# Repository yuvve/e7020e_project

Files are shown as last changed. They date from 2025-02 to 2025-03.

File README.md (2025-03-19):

# Sea Breeze Clock

The Sea Breeze Clock provides ultimate comfort for deep sleepers. Featuring a built-in humidifier, temperature sensor displayed on screen, and a gentle wake-up vibration function, it is designed to help you start your day feeling refreshed as if you have woken up on a private island.

## Members

- Yuval Levy (yuvlev-1@student.ltu.se)
- Calle Rautio (calrau-1@student.ltu.se)
- Simon Larsson (simlar-0@student.ltu.se)

## Hardware Features

- Display
- Humidifier for sea effect
- Backup battery for RTC and alarm time
- Speaker
- User interface (encoder / button)
- Programming interface
- Temperature measurement
- Fan for (hamster sized) sea breeze effect
- USB MINI connection
- Haptic actuator for SUPER GENTLE WAKE
- Hard(ish) protective case for the board

## Functionality and SW features

Besides mandatory functionality the Final Countdown features:

- Set Clock with long push and alarm time with short push. Change of volume with rotary button on default screen.
- CLI can control temperature sensor, speaker volume, intensity of buzzer, and fan speed control from CLI, and everything else.
- Maybe additional features.

## Individual grading goals and contributions

### Yuval Levy
#### 3 
- Contribute to the mandatory goals
#### 4
- Backup battery (HW & SW)
- Haptic actuator (HW & SW)
#### 5 
- Speaker (HW & SW)
- Power optimization (SW)
- Humidifier HW

### Calle Rautio
#### 3 
- Contribute to the mandatory goals
#### 4
- Humidifier SW
- Fan HW
- Fan SW
- HW component optimization (fewer MOSFETS)
#### 5 
- Speaker (HW & SW)

### Simon Larsson
#### 3 
- Contribute to the mandatory goals
#### 4
- Backup battery (HW & SW)
- Temperature on display SW
- Rotary encoder HW
#### 5 
- Speaker (HW & SW)
- Rotary encoder SW
- Power optimization (SW)

## HW References

- [MCU (QDAA QFN40)](https://docs.nordicsemi.com/bundle/ps_nrf52833/page/keyfeatures_html5.html) (**included**)
- [I2C Display](https://se.farnell.com/midas/mdob128032gv-wi/oled-display-cob-128-x-32-pixel/dp/3407291)
- [Humidifier for sea effect]() **DATASHEET MISSING!** [application](https://media.discordapp.net/attachments/1330909785532403752/1331984447591157781/temp.jpg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) (**included**)
- [Holder for backup battery (CR2032)](https://se.rs-online.com/web/p/battery-holders/7188457?gb=s)
- [Miniature speaker](https://se.rs-online.com/web/p/miniature-speakers/2596233)
- [DAC and amplifier for the speaker](https://se.farnell.com/analog-devices/max98357aete-t/audio-power-amp-d-40-to-85deg/dp/2949165)
- [Haptic Actuator](https://se.farnell.com/pui-audio/hd-emc1203-lw20-r/dc-motor-3vdc-26ohm-12000rpm/dp/4411154)
- [Rotary encoder, preferably with built-in button](https://se.rs-online.com/web/p/mechanical-rotary-encoders/7377773) (**included**)
- [Push button for resetting the program]() (**included**, alternatives:  TE Connectivity 1825910-7,  Alps Alpine STTSKHHBS) (**included**)
- [Fan for wind effect](https://se.rs-online.com/web/p/axial-fans/2887621?gb=s) (hamster sized)
- [LED](https://se.rs-online.com/web/p/leds/2648165) (**included**)
- USB Mini (**included**)
- [Analog temperature sensor](https://www.digikey.se/sv/products/detail/epcos-tdk-electronics/B57891M0103K000/3500546) (**included**)
- Serial programming header (**included**)
- Serial communication header to host, over dev-kit VCP (**included**)
- Case made either of wood or 3D-printed
### Other Parts
- Schottky diode ZLLS500TA ([link1](https://se.rs-online.com/web/p/schottky-diodes-rectifiers/0155096?gb=s), [link2](https://se.rs-online.com/web/p/schottky-diodes-rectifiers/1219937?gb=s)) x 3 (3 per board)

## SW References

**Crates/dependencies used in the project:**

- **[heapless](https://crates.io/crates/heapless/0.7.16)** – Fixed-capacity collections  
- **[cortex-m](https://docs.rs/cortex-m)** – Low-level access to Cortex-M processors  
- **[cortex-m-rtic](https://crates.io/crates/cortex-m-rtic/1.1.4)** – Real-time interrupt-driven concurrency  
- **[cortex-m-rt](https://crates.io/crates/cortex-m-rt/0.7.3)** – Minimal runtime for Cortex-M  
- **[embedded-hal](https://crates.io/crates/embedded-hal/0.2.7)** – Hardware abstraction layer for embedded systems  
- **[panic-rtt-target](https://crates.io/crates/panic-rtt-target/0.2.0)** – RTT-based panic handler  
- **[panic-halt](https://crates.io/crates/panic-halt/1.0.0)** – Halts execution on panic  
- **[rtt-target](https://crates.io/crates/rtt-target/0.6.1)** – Real-time tracing for embedded devices  
- **[systick-monotonic](https://crates.io/crates/systick-monotonic/1.0.0)** – Monotonic timer using SysTick  
- **[dwt-systick-monotonic](https://crates.io/crates/dwt-systick-monotonic/1.0.0)** – Monotonic timer using DWT and SysTick  
- **[nb](https://crates.io/crates/nb/1.1.0)** – Non-blocking operations abstraction  
- **[usb-device](https://crates.io/crates/usb-device/0.3.2)** – USB stack for embedded systems  
- **[usbd-serial](https://crates.io/crates/usbd-serial/0.2.2)** – USB-to-serial converter  
- **[usbd-hid](https://crates.io/crates/usbd-hid/0.8.2)** – USB HID implementation  
- **[embedded-graphics](https://crates.io/crates/embedded-graphics/0.8.1)** – Graphics library for embedded displays  
- **[ssd1306](https://crates.io/crates/ssd1306/0.9.0)** – Driver for SSD1306 OLED displays  
- **[libm](https://crates.io/crates/libm/0.2.11)** – Math library for no_std environments  
- **[profont](https://crates.io/crates/profont/0.7.0)** – Monospace bitmap font for embedded graphics  
- **[nrf52833-hal](https://crates.io/crates/nrf52833-hal/0.18.0)** – HAL for nRF52833 microcontrollers

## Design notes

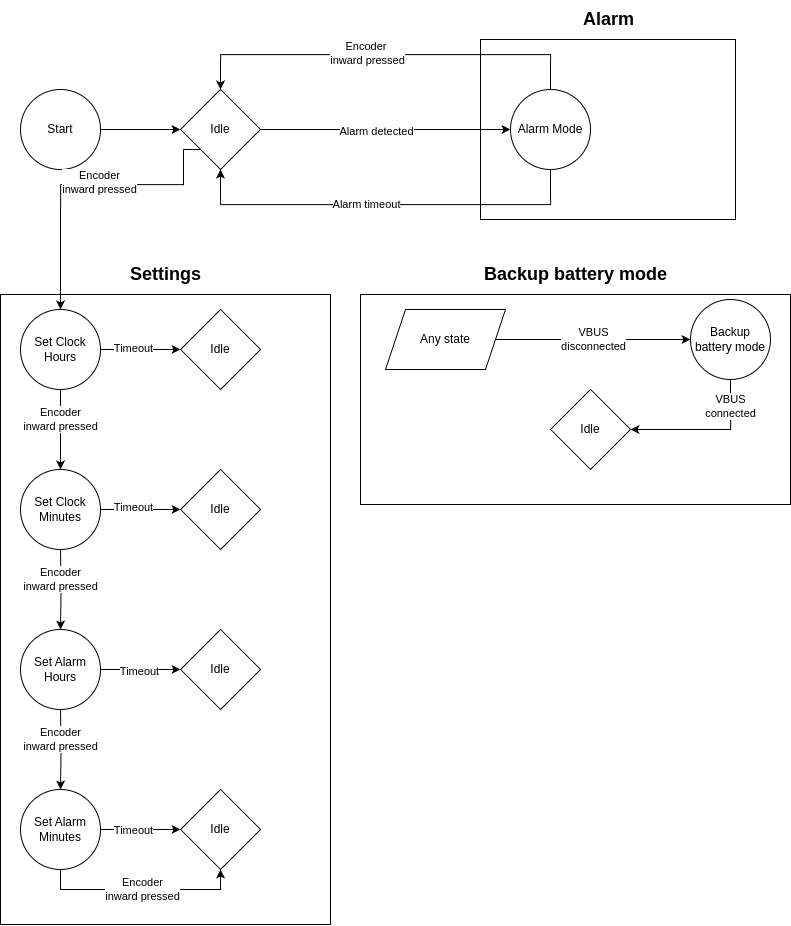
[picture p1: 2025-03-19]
software/State Machine.drawio.png

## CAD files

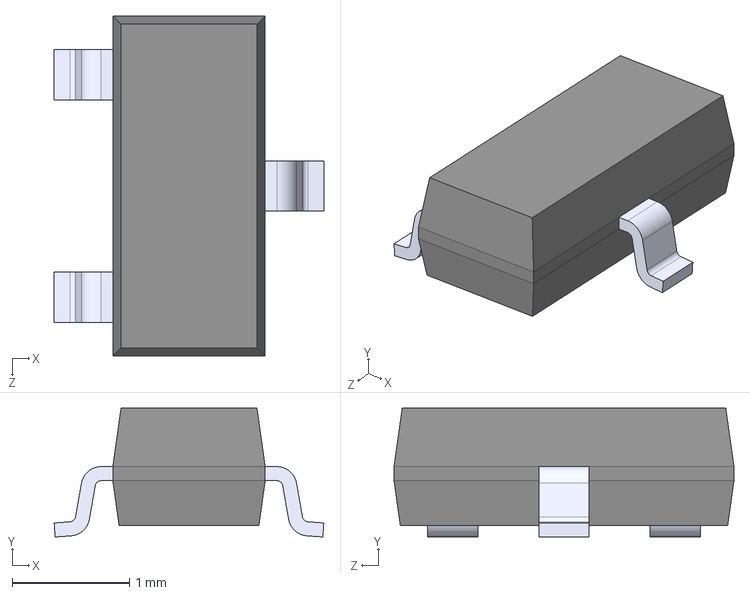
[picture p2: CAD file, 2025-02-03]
hardware/assets/BJT SMD Transistor (MMBT2222A_DG_215)/MMBT2222A_DG_215.step
2.30 x 1.10 x 2.90 mm

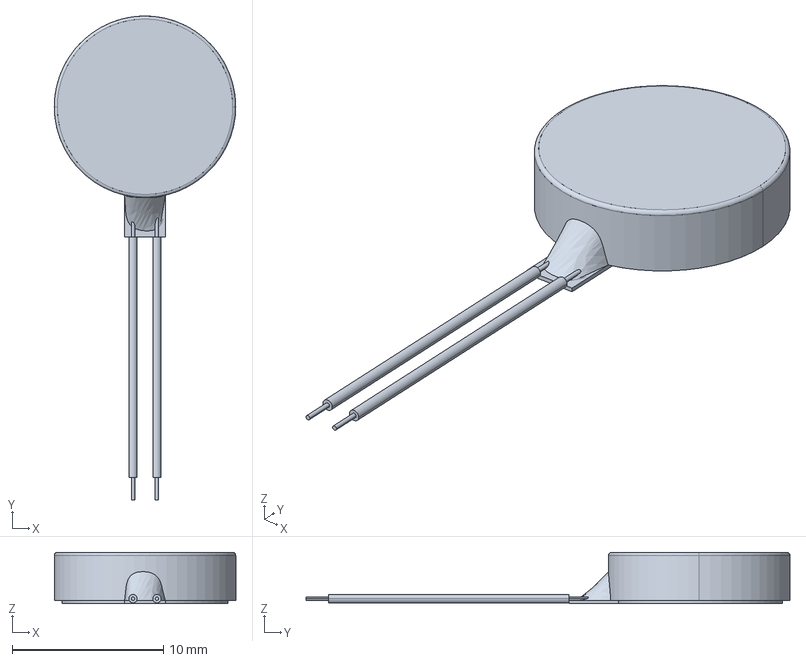
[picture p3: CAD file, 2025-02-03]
hardware/assets/Haptic Actuator (HD-EMC1203-LW20-R)/HD-EMC1203-LW20-R.step
12.0 x 32.0 x 3.40 mm

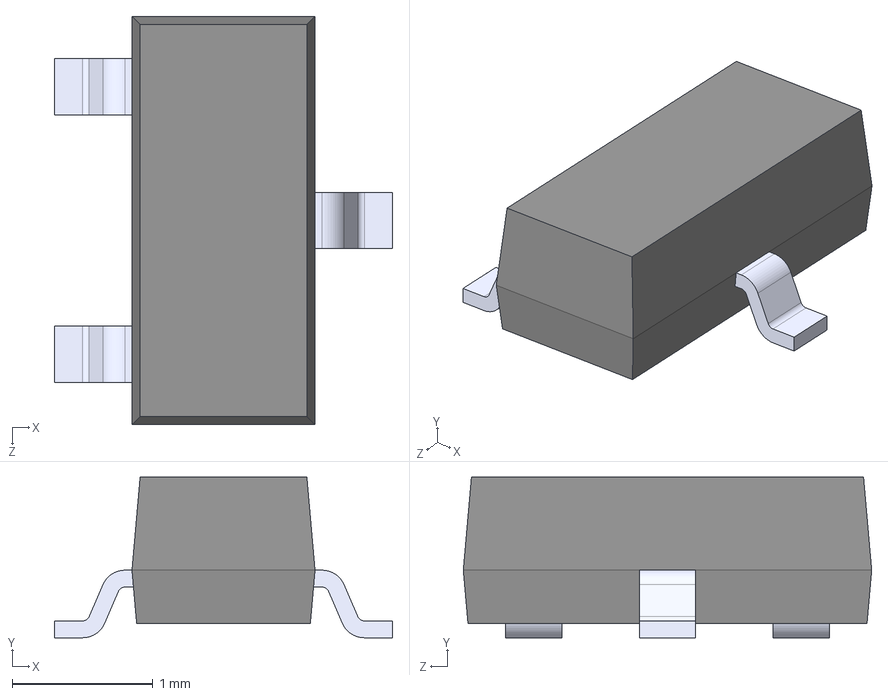
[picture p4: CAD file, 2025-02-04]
hardware/assets/Schottky Diode (ZLLS500TA)/ZLLS500TA.step
2.40 x 1.14 x 2.90 mm

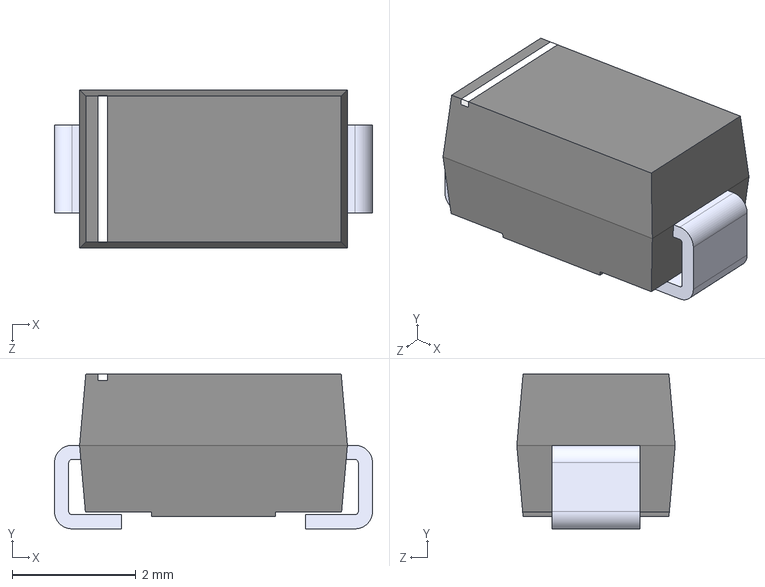
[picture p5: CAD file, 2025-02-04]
hardware/assets/Schottky Rectifier (SS16)/SS16.step
5.14 x 2.50 x 2.56 mm

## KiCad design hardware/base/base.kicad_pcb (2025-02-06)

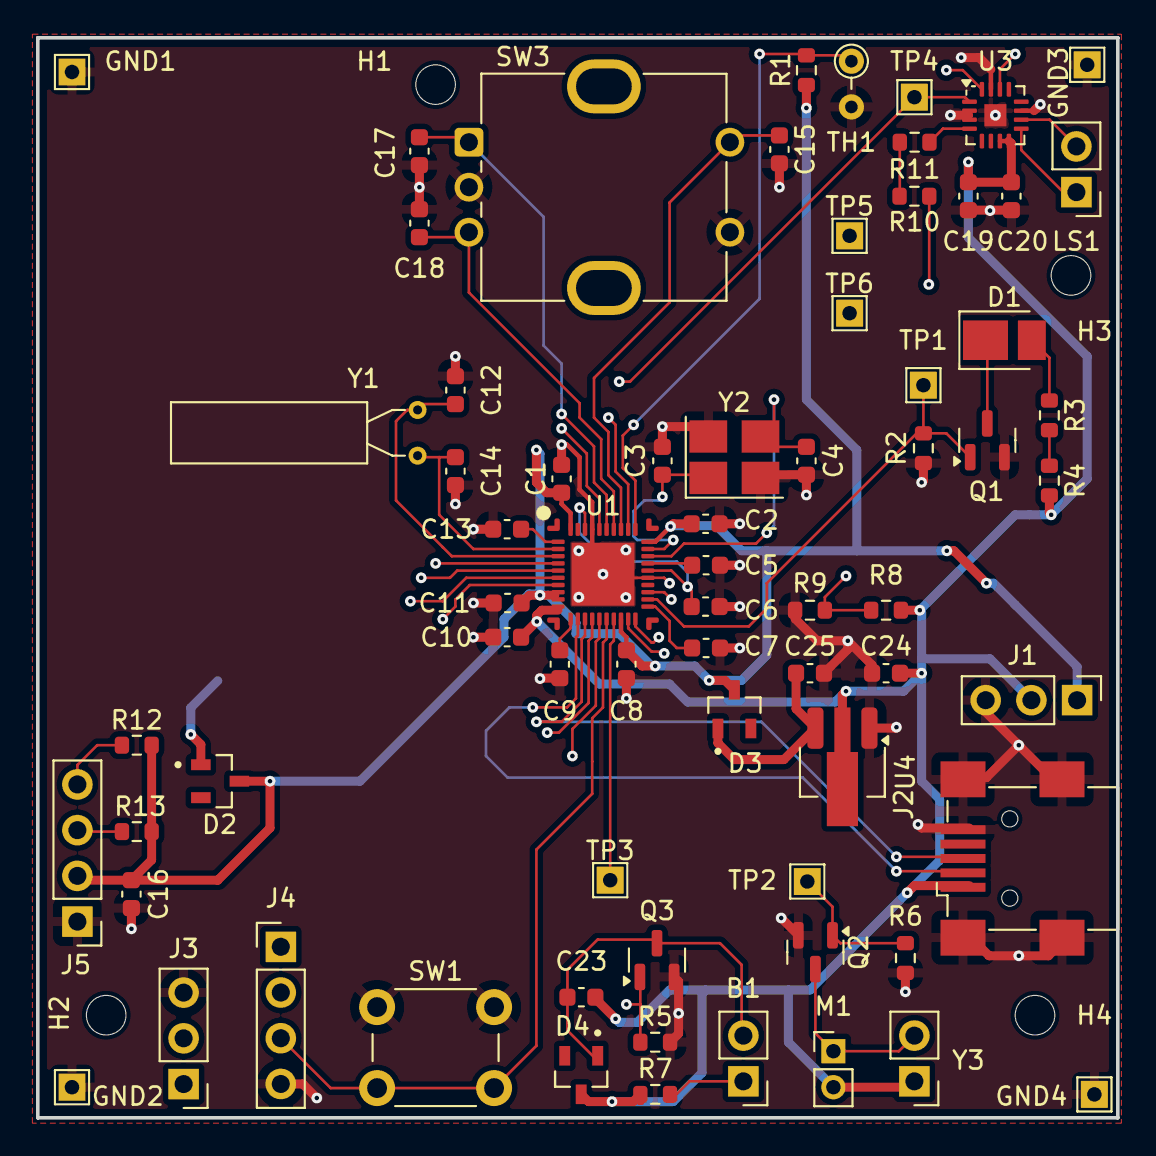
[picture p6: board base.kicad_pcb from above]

Board: 4 copper layers, 60.0 x 60.0 mm, 75 parts (1 on the bottom side), 44 nets.

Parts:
B1: HD-EMC1203-LW20-R; PinHeader_1x02_P2.54mm_Vertical
BT1: Battery_Cell; TE_796136-1
C1, C6, C16: 1uF; C_0603_1608Metric
C2, C13: 100nF; C_0603_1608Metric
C3, C4, C12, C14: 12pF; C_0603_1608Metric
C5: 100pF; C_0603_1608Metric
C7: 820pF; C_0603_1608Metric
C8: 100nf; C_0603_1608Metric
C9: 4.7uf; C_0603_1608Metric
C10, C11: 4.7uF; C_0603_1608Metric
C15, C17, C18: 10nF; C_0603_1608Metric
C19: 0.1uF; C_0603_1608Metric
C20: 10uF; C_0603_1608Metric
C23: 0.1 uF; C_0603_1608Metric
C24, C25: 1.0 uF; C_0603_1608Metric
D1: LED; LED_PLCC_2835_Handsoldering
D2, D3, D4: D_Schottky_1_3; SOT91P240X110-3N
GND1, GND2, GND3, GND4: TestPoint; TestPoint_THTPad_1.5x1.5mm_Drill0.8mm
H1, H2, H3, H4: MountingHole; MountingHole_2.2mm_M2_ISO7380
J1: Debug; PinHeader_1x03_P2.54mm_Vertical
J2: USB_B_Mini; USB_Mini-B_Wuerth_65100516121_Horizontal
J3: Serial Interface; PinHeader_1x03_P2.54mm_Vertical
J4: SWD; PinHeader_1x04_P2.54mm_Vertical
J5: OLED Display; PinHeader_1x04_P2.54mm_Vertical
LS1: Speaker; PinHeader_1x02_P2.54mm_Vertical
M1: Fan_ALT; PinHeader_1x02_P2.00mm_Vertical
Q1, Q2, Q3: Q_NMOS_GSD; SOT-23
R1, R2, R5, R6, R12, R13: 10k; R_0603_1608Metric
R3, R4: 22; R_0603_1608Metric
R7: 22 Ohm; R_0603_1608Metric
R8: 68 kOhm; R_0603_1608Metric
R9: 100 kOhm; R_0603_1608Metric
R10: 150 kOhm; R_0603_1608Metric
R11: 470 kOhm; R_0603_1608Metric
SW1: SW_PUSH_6mm_H9.5mm
SW3: RotaryEncoder_Switch; RotaryEncoder_Bourns_Vertical_PEC12R-3x17F-Sxxxx
TH1: Thermistor_NTC; R_Axial_DIN0204_L3.6mm_D1.6mm_P2.54mm_Vertical
TP1, TP2, TP3, TP4, TP5, TP6: TestPoint; TestPoint_THTPad_1.5x1.5mm_Drill0.8mm
U1: nRF52833-QDxx; QFN-40-1EP_5x5mm_P0.4mm_EP3.6x3.6mm
U3: MAX98357A; TQFN-16-1EP_3x3mm_P0.5mm_EP1.23x1.23mm
U4: MCP1700x-330xxMB; SOT-89-3_Handsoldering
Y1: 32kHz; Crystal_AT310_D3.0mm_L10.0mm_Horizontal
Y2: 32MHz; Crystal_SMD_3225-4Pin_3.2x2.5mm_HandSoldering
Y3: 1.70 MHz; PinHeader_1x02_P2.54mm_Vertical

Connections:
+3.3V: C1.1, C2.1, C8.1, C11.1, C16.1, D2.3 (K), D3.3 (K), J1.1, J5.2, R1.1, R12.1, R13.1, U1.8 (VDD), U1.9 (VDDH), U1.18 (VDD), U1.30 (VDD), U1.40 (VDD)
/AMP_BCLK: TP5.1, U1.4 (P0.04/AIN2), U3.16 (BCLK)
/AMP_DIN: TP4.1, U1.36 (AIN7/P0.31), U3.1 (DIN)
/AMP_FAN_HUM: Q2.1 (G), R6.1, R10.1, TP2.1, U1.23 (NFC2/P0.10)
/AMP_LRCLK: TP6.1, U1.5 (P0.05/AIN3), U3.14 (LRCLK)
/DEC4_6: C6.2, U1.26 (DEC6), U1.38 (DEC4)
/DETECT_VSOURCE: R8.2, R9.1, U1.32 (AIN0/P0.02)
/HAPTIC: Q3.1 (G), R5.1, TP3.1, U1.17 (P0.20)
/LED: Q1.1 (G), R2.1, TP1.1, U1.22 (NFC1/P0.09)
/ROT_ENC_A: C17.1, SW3.A, U1.35 (AIN6/P0.30)
/ROT_ENC_B: C18.1, SW3.B, U1.34 (AIN5/P0.29)
/ROT_ENC_S1: C15.1, SW3.S1, U1.33 (AIN4/P0.28)
/VBUS: C10.1, C19.2, C20.2, C23.1, C24.1, D4.3 (K), J1.2, J2.1 (VBUS), M1.2 (-), R4.2, R7.1, R8.1, U1.10 (VBUS), U3.7 (VDD), U3.8 (VDD), U4.2 (VI), Y3.1
GND: BT1.2 (-), C1.2, C2.2, C3.1, C4.2, C5.2, C6.1, C7.1, C8.2, C9.2, C10.2, C11.2, C12.2, C13.2, C14.1, C15.2, C16.2, C17.2, C18.2, C19.1, C20.1, C24.2, C25.2, GND1.1, GND2.1, GND3.1, GND4.1, J1.3, J2.5 (GND), J2.6 (Shield), J3.3, J4.4, J5.1, Q1.2 (S), Q2.2 (S), Q3.2 (S), R2.2, R5.2, R6.2, R9.2, SW1.1, SW3.C, SW3.S2, TH1.2, U1.25 (VSS_PA), U1.37 (VSS), U1.41 (VSS), U3.2 (GAIN_SLOT), U3.3 (GND), U3.11 (GND), U3.15 (GND), U3.17 (PAD), U4.1 (GND), Y2.2, Y2.4
unnamed: B1.1, R7.2
unnamed: BT1.1 (+), D2.1 (A)
unnamed: D1.2 (A), R3.1
unnamed: D1.1 (K), Q1.3 (D)
unnamed: C25.1, D3.1 (A), U4.3 (VO)
unnamed: B1.2, C23.2, D4.1 (A), Q3.3 (D)
unnamed: J2.3 (D+), U1.13 (D+)
unnamed: J2.2 (D-), U1.12 (D-)
unnamed: J3.1, U1.14 (P0.15)
unnamed: J3.2, U1.15 (P0.17)
unnamed: J4.1, U1.20 (SWDCLK)
unnamed: J4.2, U1.19 (SWDIO)
unnamed: J4.3, SW1.2, U1.16 (P0.18/~RESET)
unnamed: J5.3, R13.2, U1.7 (P0.11)
unnamed: J5.4, R12.2, U1.6 (P1.09)
unnamed: M1.1 (+), Q2.3 (D), Y3.2
unnamed: R3.2, R4.1
unnamed: R10.2, R11.1
unnamed: R1.2, TH1.1, U1.31 (AIN1/P0.03)
unnamed: C13.1, U1.1 (DEC1)
unnamed: C5.1, U1.27 (DEC3)
unnamed: C7.2, U1.21 (DEC5)
unnamed: C9.1, U1.11 (DECUSB)
unnamed: C14.2, U1.2 (P0.00/XL1), Y1.2
unnamed: C12.1, U1.3 (P0.01/XL2), Y1.1
unnamed: C4.1, U1.28 (XC1), Y2.3
unnamed: C3.2, U1.29 (XC2), Y2.1
unnamed: LS1.2, U3.10 (OUTN)
unnamed: LS1.1, U3.9 (OUTP)
unnamed: R11.2, U3.4 (~SD_MODE)

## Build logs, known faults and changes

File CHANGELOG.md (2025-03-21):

# Changelog 2025

## 27.01

- Yuval: researched parts and circuits
- Calle: researched parts and circuits        let duty = 0;

- Simon: researched parts and circuits

## 28.01

- Yuval: researched parts and circuits
- Calle: researched parts and circuits
- Simon: researched parts and circuits

## 30.01

- Yuval:
  - researched parts and circuits
  - created backup battery schematics
- Calle: researched parts and circuits
- Simon: researched parts and circuits

## 31.01

- Simon: add base schematic and circuit for: oled and rotary encoder.

## 02.02

- Calle: Made a basic schematic for fan and showed potential solution to saving GPIO pins
- Yuval:
  - Add haptic actuator schematic
  - Add humidifier schematic

## 03.02

- Yuval:
  - Update humidifier schematic
  - Update haptic actuator schematic
  - Combined all schematics
- Simon:
  - Combined all schematics
- Calle:
  - Combined all schematics

## 04.02

- Calle:
  - Schematics review
  - PCB Layout
- Yuval:
  - Schematics review
  - PCB Layout
- Simon:
  - Schematics review
  - PCB Layout

## 20.02

- Yuval:
  - SMD soldering (PCB #1)
- Simon:
  - SMD soldering (PCB #1)

## 25.02

- Yuval:
  - Debugging and some hand soldering (PCB #1)
- Simon:
  - Debugging and some hand soldering (PCB #1)
- Calle:
  - Debugging and some hand soldering (PCB #1)

## 26.02

- Simon:
  - PWM dimmable LED example, set NFC pins (P0.09/10) to GPIO mode.

## 28.02

- Yuval:
  - SMD soldering (PCB #2)
- Simon:
  - SMD soldering (PCB #2)
  - Finished hand soldering (PCB #1)

## 02.03

- Simon:
  - Reset button example
  - Rotary encoder and switch example (including debouncing)

## 03.03

- Yuval:
  - Rework (PCB #2)
  - Case design (consultation)
- Simon
  - SMD soldering (PCB #3)
  - Case design (consultation)
- Calle
  - SMD soldering (PCB #3)
  - Rework (PCB #3)
  - Finished hand soldering (PCB #3)
  - Case design 
  
## 04.03

- Yuval:
  - Finished hand soldering (PCB #2)

## 05.03

- Yuval:
  - Design and implement state machine

## 06.03

- Yuval:
  - Backup mode initial
- Simon:
  - Thermistor example

## 07.03

- Yuval:
  - Backup mode working
  - Serial over USB
- Simon:
  - RTC timer and alarm

## 09.03

- Calle:
  - Finshed Fan_SW

## 11.03

- Calle:
  - Got the display to show what we want, but it does not correctly display the current time or temperature.

## 13.03

- Yuval:
  - Haptic actuator example
  - A little work on speaker
- Simon:
  - Integrate RTC into state machine

## 15.03

- Simon:
  - Integrate thermistor into state machine

## 16.03

- Simon:
  - Integrate rotary encoder and reset button into state machine

## 17.03

- Simon:
  - Integrate PWM and LED into state machine
  - Integrate fan, humidifier and haptic actuator. PWM levels not tested.
  - Integrate display into state machine. Not tested on OLED.

## 18.03

- Yuval:
  - add CLI example
- Simon:
  - Add separate PWM sequences for LED, amp/fan/hum and haptic actuator

## 19.03

- Yuval:
  - Worked on fixing minor bugs and finalizing the case
- Calle:
  - Created three cases with accompanying rotary buttons and worked on getting the speaker to function
- Simon:
  - Worked on fixing minor bugs and finalizing the case
  - Finished display integration

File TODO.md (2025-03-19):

# TODO
Look at the CHANGELOG for each person's contributions.
## Minimal requirements
- [x] Real-time clock (RTC) based on 32kHz crystal
- [x] At least one function button
- [x] PWM modulated LED with transistor driver
- [x] Sound on alarm, e.g., buzzer
- [x] Analog input, e.g., temperature/supply voltage
- [x] Serial communication interface e.g., using dev-kit, Virtual Com Port (VCP)
- [x] Command Line Interface (CLI) for simple host interaction
- [x] Display that shows current time

## Extra Grade 4
- [x] Humidifier SW
- [x] HW component optimization (fewer MOSFETS)
- [x] Haptic actuator HW
- [X] Haptic actuator SW
- [x] Serial over USB
- [x] Backup battery HW
- [x] Backup battery SW
- [x] Rotary encoder HW
- [x] Fan HW
- [x] Fan SW
- [x] Temperature on display SW

## Extra Grade 5
- [x] Speaker HW
- [/] Speaker SW
- [x] Humidifier HW
- [ ] Power optimization SW
- [x] Rotary encoder SW

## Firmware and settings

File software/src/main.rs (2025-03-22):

#![no_main]
#![no_std]
#![allow(dead_code)]
//#![deny(unsafe_code)]
#![deny(warnings)]

mod rtt;
mod display;
mod gpio;
mod pwm;
mod rotary_encoder;
mod rtc;
mod state_machine;
mod thermistor;
mod uicr;
mod backup_mode;
mod cli;
mod speaker;

use {
    cli::*,
    crate::{display::Display, pwm::Pwm0, state_machine::*},
    core::sync::atomic::{AtomicU32, AtomicBool, Ordering},
    cortex_m::asm,
    hal::{
        gpio::*,
        gpiote::*,
        qdec::*,
        rtc::*,
        saadc::*,
        lpcomp::LpComp,
        clocks::{
            Clocks,
            ExternalOscillator,
            Internal,
            LfOscStarted,
        },
        usbd::{
            Usbd,
            UsbPeripheral
        },
    },
    nrf52833_hal as hal, 
    panic_rtt_target as _,
    rtt_target::UpChannel,
    usb_device::device::UsbDevice,
    usbd_serial::{SerialPort, USB_CLASS_CDC},

    usb_device::{
        class_prelude::UsbBusAllocator,
        device::{StringDescriptors, UsbDeviceBuilder, UsbVidPid},
    },
};

#[cfg(feature = "52833-debug")]
use {
    core::fmt::Write,
    rtt_target::rprintln,
};

#[rtic::app(device = nrf52833_hal::pac, dispatchers= [TEMP, RNG, ECB, FPU, PDM, CCM_AAR, SWI5_EGU5])]
mod app {
    use super::*;

    #[shared]
    struct Shared {
        rtt_hw: UpChannel,
        rtt_serial: UpChannel,
        rtc: Rtc<hal::pac::RTC1>,
        time_offset_ticks: AtomicU32,  // Time offset in ticks from 00:00
        alarm_offset_ticks: AtomicU32, // Alarm offset in ticks from 00:00
        amp_on: AtomicBool,
        temperature: f32,
        #[lock_free]
        pwm: Pwm0,
        display: Display,
        amp_fan_hum_pin: Pin<Output<PushPull>>,
        #[lock_free]
        usb_dev: UsbDevice<'static, Usbd<UsbPeripheral<'static>>>,
        #[lock_free]
        serial: SerialPort<'static, Usbd<UsbPeripheral<'static>>>, 
        gpiote: Gpiote,
        qdec: Qdec,
    }

    #[local]
    struct Local {
        rtt_display: UpChannel,
        rtt_state: UpChannel,
        rtt_speaker: UpChannel,
        state_machine: State,
        saadc: Saadc,
        saadc_pin: p0::P0_03<Disconnected>,
        comp: LpComp,
        dma_buf: [u32; speaker::BUFFER_LEN],
        i2s: Option<hal::i2s::I2S>,
    }

    #[init(local = [
        SEQBUF0: [u16; pwm::SEQUENCE_LENGTH*4] = [0u16; pwm::SEQUENCE_LENGTH*4],
        SEQBUF1: [u16; pwm::SEQUENCE_LENGTH*4] = [0u16; pwm::SEQUENCE_LENGTH*4],
        clocks: Option<Clocks<ExternalOscillator, Internal, LfOscStarted>> = None,
        usb_bus: Option<UsbBusAllocator<Usbd<UsbPeripheral<'static>>>> = None, 
    ])]
    fn init(mut cx: init::Context) -> (Shared, Local, init::Monotonics) {
        let (rtt_display, rtt_hw, rtt_state, rtt_serial, rtt_speaker) = rtt::init();

        let SEQBUF0 = cx.local.SEQBUF0;
        let SEQBUF1 = cx.local.SEQBUF1;

        //Enable USBD interrupt
        cx.device.USBD.intenset.write(|w| w.sof().set());

        // Need to set up the 32kHz clock source for the RTC
        let clocks = hal::clocks::Clocks::new(cx.device.CLOCK);

        // make static lifetime for clocks
        cx.local.clocks.replace(clocks.enable_ext_hfosc().start_lfclk());

        let usb_bus = UsbBusAllocator::new(Usbd::new(UsbPeripheral::new(
            cx.device.USBD,
            // refer to static lifetime
            cx.local.clocks.as_ref().unwrap(),
        )));
        cx.local.usb_bus.replace(usb_bus);

        let serial = SerialPort::new(&cx.local.usb_bus.as_ref().unwrap());

        let usb_dev = UsbDeviceBuilder::new(
            &cx.local.usb_bus.as_ref().unwrap(),
            UsbVidPid(0x16c0, 0x27dd),
        )
        .strings(&[StringDescriptors::default()
        .manufacturer("Fake company")
        .product("Serial port")
        .serial_number("TEST")])
        .unwrap()
        .device_class(USB_CLASS_CDC)
        .max_packet_size_0(64) // (makes control transfers 8x faster)
        .unwrap()
        .build();

        // Enable cycle counter
        cx.core.DCB.enable_trace();
        cx.core.DWT.enable_cycle_counter();

        // Initialize GPIO pins
        let pins = gpio::init(cx.device.P0, cx.device.P1);

        // Initialize UICR
        uicr::init(cx.device.UICR, cx.device.NVMC);

        // Initialize PWM
        let pwm = pwm::init(cx.device.PWM0, pins.led, pins.haptic);
        let pwm = pwm.load(Some(SEQBUF0), Some(SEQBUF1), false).ok();
        load_pwm_sequence::spawn().ok();

        // Initialize the RTC peripheral
        let rtc = rtc::init(cx.device.RTC1);

        // Initialize the rotary encoder and switch
        let (qdec, gpiote) = rotary_encoder::init(
            cx.device.QDEC,
            cx.device.GPIOTE,
            pins.rotary_encoder,
            pins.rotary_switch,
        );

        // Initialize the OLED display
        let display = display::init(cx.device.TWIM0, pins.oled);

        // Initialize the thermistor, read initial temp
        let saadc = thermistor::init(cx.device.SAADC);
        read_temperature::spawn().ok();

        // Simulate user setting the time
        let time_ticks = rtc::time_to_ticks(06, 20);
        set_time::spawn(time_ticks).ok();

        // Simulate user setting the alarm,
        let alarm_ticks = rtc::time_to_ticks(06, 21);
        set_alarm::spawn(alarm_ticks).ok();

        let comp = backup_mode::init(cx.device.LPCOMP, pins.vdetect);

        let i2s = speaker::init(cx.device.I2S, pins.speaker);
        enable_display::spawn().ok();
        (
            Shared {
                rtt_serial,
                rtt_hw,
                rtc,
                time_offset_ticks: AtomicU32::new(time_ticks),
                alarm_offset_ticks: AtomicU32::new(alarm_ticks),
                amp_on: AtomicBool::new(false),
                temperature: 0.0,
                pwm,
                display,
                amp_fan_hum_pin: pins.amp_fan_hum,
                usb_dev,
                serial,
                gpiote,
                qdec,
            },
            Local {
                rtt_display,
                rtt_state,
                rtt_speaker,
                state_machine: State::Idle,
                saadc,
                saadc_pin: pins.saadc,
                comp,
                dma_buf: [0u32; speaker::BUFFER_LEN],
                i2s: Some(i2s),
            },
            init::Monotonics(),
        )
    }

    #[idle]
    fn idle(_cx: idle::Context) -> ! {
        #[cfg(feature = "52833-debug")]
        rprintln!("idle");
        loop {
            asm::wfi();
        }
    }

    #[task(
        priority = 4, 
        capacity = 10, 
        local = [state_machine, current_ticks: u32 = 0, temp_ticks: u32 = 0, rtt_state], 
        shared = [&time_offset_ticks, &alarm_offset_ticks, &amp_on])]
    fn state_machine(cx: state_machine::Context, event: Event) {
        let state = *cx.local.state_machine;
        let next_state = state.next(event);
        *cx.local.state_machine = next_state;
        #[cfg(feature = "52833-debug")]
        writeln!(
            cx.local.rtt_state, 
            "State: {:?}, Event: {:?} -> State: {:?}", state, event, next_state
        ).ok();

        match event {
            Event::Timer(TimerEvent::PeriodicUpdate(counter)) => {
                let new_time = cx.shared.time_offset_ticks.load(Ordering::Relaxed)
                    + counter % rtc::TICKS_PER_DAY;
                *cx.local.current_ticks = new_time;
                read_temperature::spawn().ok();
                set_periodic_update::spawn(rtc::TICKS_PER_MINUTE).ok();

                match state {
                    State::Idle => {
                        update_display::spawn(new_time, display::Section::Display, false).ok();
                    }
                    _ => {}
                }
            }
            Event::Timer(TimerEvent::AlarmTriggered) => {
                match state {
                    State::Idle => {
                        cx.shared.amp_on.store(true, Ordering::Relaxed); 
                        turn_on_amp_fan_hum::spawn().ok();
                        disable_alarm::spawn().ok();
                        start_pwm::spawn().ok();
                        update_display::spawn(*cx.local.current_ticks, display::Section::AlarmIcon, false).ok();
                        play_next_audio_segment::spawn().ok();
                    }
                    _ => {}
                }
            }
            Event::Timer(TimerEvent::Timeout) => {
                match state {
                    State::Settings(_) => {
                        disable_blinking::spawn().ok();
                        update_display::spawn(*cx.local.current_ticks, display::Section::Display, false).ok();
                    }
                    State::Alarm => {
                        disable_alarm_components(&cx);
                        update_display::spawn(*cx.local.current_ticks, display::Section::Display, false).ok();
                    }
                    _ => {}
                }
            }
            Event::Timer(TimerEvent::Blink) => {
                match state {
                    State::Alarm => {
                        update_display::spawn(*cx.local.current_ticks, display::Section::AlarmIcon, true).ok();
                        set_blinking::spawn(rtc::BLINK_TICKS).ok();

                    }
                    State::Settings(settings) => match settings {
                        Settings::ClockHours => {
                            update_display::spawn(*cx.local.temp_ticks, display::Section::Hour, true).ok();
                            set_blinking::spawn(rtc::BLINK_TICKS).ok();

                        }
                        Settings::ClockMinutes => {
                            update_display::spawn(*cx.local.temp_ticks, display::Section::Minute, true).ok();
                            set_blinking::spawn(rtc::BLINK_TICKS).ok();

                        }
                        Settings::AlarmHours => {
                            update_display::spawn(*cx.local.temp_ticks, display::Section::Hour, true).ok();
                            set_blinking::spawn(rtc::BLINK_TICKS).ok();

                        }
                        Settings::AlarmMinutes => {
                            update_display::spawn(*cx.local.temp_ticks, display::Section::Minute, true).ok();
                            set_blinking::spawn(rtc::BLINK_TICKS).ok();
                        }
                    },
                    _ => {}
                }
            }
            Event::Encoder(EncoderEvent::ShortPressed) => match state {
                State::Idle => {
                    let alarm_time = cx.shared.alarm_offset_ticks.load(Ordering::Relaxed);
                    *cx.local.temp_ticks = alarm_time;

                    disable_alarm::spawn().ok();
                    set_timeout::spawn(rtc::TIMEOUT_SETTINGS_TICKS).ok();
                    set_blinking::spawn(rtc::BLINK_TICKS).ok();
                    update_display::spawn(alarm_time, display::Section::Display, false).ok();
                }
                State::Alarm => {
                    disable_alarm_components(&cx);
                    update_display::spawn(*cx.local.current_ticks, display::Section::Display, false).ok();
                }
                State::Settings(settings) => match settings {
                    Settings::ClockMinutes => {
                        *cx.local.current_ticks = *cx.local.temp_ticks;
                        disable_blinking::spawn().ok();
                        set_time::spawn(*cx.local.temp_ticks).ok();
                        set_alarm::spawn(cx.shared.alarm_offset_ticks.load(Ordering::Relaxed)).ok();
                        update_display::spawn(*cx.local.temp_ticks, display::Section::Display, false).ok();
                        set_periodic_update::spawn(rtc::TICKS_PER_MINUTE).ok();
                    }
                    Settings::AlarmMinutes => {
                        set_alarm::spawn(*cx.local.temp_ticks).ok();
                        disable_blinking::spawn().ok();
                        update_display::spawn(*cx.local.current_ticks, display::Section::Display, false).ok();
                    }
                    _ => {}
                },
                _ => {}
            },
            Event::Encoder(EncoderEvent::LongPressed) => match state {
                State::Idle => {
                    let temp = *cx.local.current_ticks;
                    *cx.local.temp_ticks = temp;

                    disable_periodic_update::spawn().ok();
                    disable_alarm::spawn().ok();
                    set_blinking::spawn(rtc::BLINK_TICKS).ok();
                    set_timeout::spawn(rtc::TIMEOUT_SETTINGS_TICKS).ok();
                }
                State::Alarm => {
                    disable_alarm_components(&cx);
                    update_display::spawn(*cx.local.current_ticks, display::Section::Display, false).ok();
                }
                _ => {}
            },
            Event::Encoder(EncoderEvent::Rotated(direction)) => {
                match state {
                    State::Settings(settings) => {
                        let mut diff = direction;
                        match settings {
                            Settings::ClockHours => {
                                diff = diff * rtc::TICKS_PER_HOUR as isize;
                                let temp = *cx.local.temp_ticks;
                                let new_time = (temp as isize + diff).rem_euclid(rtc::TICKS_PER_DAY as isize) as u32;
                                *cx.local.temp_ticks = new_time;
                            }
                            Settings::ClockMinutes => {
                                diff = diff * rtc::TICKS_PER_MINUTE as isize;
                                let temp = *cx.local.temp_ticks;
                                let new_time = (temp as isize + diff).rem_euclid(rtc::TICKS_PER_DAY as isize) as u32;
                                *cx.local.temp_ticks = new_time;
                            }
                            Settings::AlarmHours => {
                                diff = diff * rtc::TICKS_PER_HOUR as isize;
                                let temp = *cx.local.temp_ticks;
                                let new_time = (temp as isize + diff).rem_euclid(rtc::TICKS_PER_DAY as isize) as u32;
                                *cx.local.temp_ticks = new_time;
                            }
                            Settings::AlarmMinutes => {
                                diff = diff * rtc::TICKS_PER_MINUTE as isize;
                                let temp = *cx.local.temp_ticks;
                                let new_time = (temp as isize + diff).rem_euclid(rtc::TICKS_PER_DAY as isize) as u32;
                                *cx.local.temp_ticks = new_time;
                            }
                        }
                    }
                    _ => {}
                }
            }
            Event::VBUSConnected => {
                match state {
                    State::BackupBattery => { // Just in case
                        set_alarm::spawn(*cx.local.current_ticks).ok();
                        set_periodic_update::spawn(rtc::TICKS_PER_MINUTE).ok();
                        rotary_encoder_enable_interrupts::spawn().ok();
                        enable_display::spawn().ok();
                        update_display::spawn(*cx.local.current_ticks, display::Section::Display, false).ok();
                    }
                    _ => {}
                }
            }
            Event::VBUSDisconnected => {
                match state {
                    State::BackupBattery => {} // Just in case
                    _ => {
                        rotary_disable_interrupts::spawn().ok();
                        disable_alarm::spawn().ok();
                        disable_periodic_update::spawn().ok();
                        disable_timeout::spawn().ok();
                        disable_display::spawn().ok();
                        disable_alarm_components(&cx);
                    }
                }
            }
            _ => {}
        }
    }

    #[task(binds = RTC1, priority = 4, shared = [rtc, &time_offset_ticks, rtt_hw])]
    fn rtc_interrupt(cx: rtc_interrupt::Context) {
        rtc::handle_interrupt(cx);
    }

    #[task(binds = QDEC, priority = 4,  local = [last_rotation: u32 = 0], shared = [rtt_hw, qdec])]
    fn qdec_interrupt(cx: qdec_interrupt::Context) {
        rotary_encoder::handle_qdec_interrupt(cx);
    }

    #[task(binds = GPIOTE, priority = 4, local = [last_press: u32 = 0], shared = [gpiote, rtt_hw])]
    fn gpiote_interrupt(cx: gpiote_interrupt::Context) {
        rotary_encoder::handle_gpiote_interrupt(cx);
    }

    #[task(binds = COMP_LPCOMP, priority = 5, local = [comp], shared=[rtt_hw])]
    fn comp_lcomp(cx: comp_lcomp::Context) {
        backup_mode::comp_lcomp(cx);
    }

    #[task(binds=USBD, priority = 4, shared = [usb_dev, serial, rtt_hw])]
    fn usb_fs(cx: usb_fs::Context) {
        cli::usb_fs(cx);
    }

    #[task(shared = [gpiote, rtt_hw, qdec], priority = 5)]
    fn rotary_disable_interrupts(cx: rotary_disable_interrupts::Context) {
        rotary_encoder::disable_interrupts(cx);
    }

    #[task(shared = [gpiote, rtt_hw, qdec], priority = 3)]
    fn rotary_encoder_enable_interrupts(cx: rotary_encoder_enable_interrupts::Context) {
        rotary_encoder::enable_interrupts(cx);
    }

    #[task(priority = 3, shared = [rtc, &time_offset_ticks])]
    fn set_time(cx: set_time::Context, ticks: u32) {
        #[cfg(feature = "52833-debug")]
        rprintln!("Setting time, ticks: {}", ticks);
        rtc::set_time(cx, ticks);
    }

    #[task(priority = 3, shared = [rtc, &alarm_offset_ticks, &time_offset_ticks])]
    fn set_alarm(cx: set_alarm::Context, ticks: u32) {
        #[cfg(feature = "52833-debug")]
        rprintln!("Setting alarm, ticks: {}", ticks);
        rtc::set_alarm(cx, ticks);
    }

    #[task(priority = 5, shared = [rtc])]
    fn disable_alarm(cx: disable_alarm::Context) {
        #[cfg(feature = "52833-debug")]
        rprintln!("Disabling alarm");
        rtc::disable_alarm(cx);
    }

    #[task(priority = 1, shared = [rtc])]
    fn set_periodic_update(cx: set_periodic_update::Context, interval_minutes: u32) {
        #[cfg(feature = "52833-debug")]
        rprintln!("Setting periodic update, ticks: {}", interval_minutes);
        rtc::set_periodic_update(cx, interval_minutes);
    }

    #[task(priority = 5, shared = [rtc])]
    fn disable_periodic_update(cx: disable_periodic_update::Context) {
        #[cfg(feature = "52833-debug")]
        rprintln!("Disabling periodic update");
        rtc::disable_periodic_update(cx);
    }

    #[task(priority = 3, shared = [rtc, &time_offset_ticks])]
    fn set_timeout(cx: set_timeout::Context, ticks: u32) {
        #[cfg(feature = "52833-debug")]
        rprintln!("Setting timeout, ticks: {}", ticks);
        rtc::set_timeout(cx, ticks);
    }

    #[task(priority = 3, shared = [rtc])]
    fn disable_timeout(cx: disable_timeout::Context) {
        #[cfg(feature = "52833-debug")]
        rprintln!("Disabling timeout");
        rtc::disable_timeout(cx);
    }

    #[task(priority = 3, shared = [rtc])]
    fn set_blinking(cx: set_blinking::Context, interval_ticks: u32) {
        #[cfg(feature = "52833-debug")]
        rprintln!("Setting blinking, interval_ticks: {}", interval_ticks);
        rtc::set_blinking(cx, interval_ticks);
    }

    #[task(priority = 5, shared = [rtc])]
    fn disable_blinking(cx: disable_blinking::Context) {
        #[cfg(feature = "52833-debug")]
        rprintln!("disable_blinking");
        rtc::disable_blinking(cx);
    }

    #[task(priority = 3, local = [saadc, saadc_pin], shared = [temperature])]
    fn read_temperature(cx: read_temperature::Context) {
        #[cfg(feature = "52833-debug")]
        rprintln!("read_temperature");
        thermistor::read(cx);
    }

    #[task(priority = 3, shared = [pwm])]
    fn load_pwm_sequence(cx: load_pwm_sequence::Context) {
        #[cfg(feature = "52833-debug")]
        rprintln!("load_pwm_sequence");
        pwm::load_pwm_sequence(cx);
    }

    #[task(priority = 3, shared = [pwm])]
    fn start_pwm(cx: start_pwm::Context) {
        #[cfg(feature = "52833-debug")]
        rprintln!("start_pwm");
        pwm::start(cx);
    }

    #[task(priority = 3, shared = [pwm])]
    fn stop_pwm(cx: stop_pwm::Context) {
        #[cfg(feature = "52833-debug")]
        rprintln!("stop_pwm");
        pwm::stop(cx);
    }

    #[task(priority = 5, shared = [display, temperature], local = [on: bool = true, rtt_display])]
    fn update_display(
        cx: update_display::Context,
        ticks: u32,
        section: display::Section,
        blink: bool,
    ) {
        #[cfg(feature = "52833-debug")]
        rprintln!("update_display");
        //display::update_display_rtt(cx, ticks, section, blink);
        display::update_display(cx, ticks, section, blink);
    }

    #[task(priority = 3, shared = [display])]
    fn enable_display(cx: enable_display::Context) {
        #[cfg(feature = "52833-debug")]
        rprintln!("enable_display");
        display::enable_display(cx);
    }

    #[task(priority = 5, shared = [display])]
    fn disable_display(cx: disable_display::Context) {
        #[cfg(feature = "52833-debug")]
        rprintln!("disable_display");
        display::disable_display(cx);
    }

    #[task(priority = 3, shared = [amp_fan_hum_pin])]
    fn turn_on_amp_fan_hum(cx: turn_on_amp_fan_hum::Context) {
        #[cfg(feature = "52833-debug")]
        rprintln!("turn_on_amp_fan_hum");
        gpio::turn_on_amp_fan_hum(cx);
    }
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

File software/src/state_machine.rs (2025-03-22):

#![allow(dead_code)]

#[derive(Clone, Copy, PartialEq, Debug)]
pub enum State {
    Idle,
    Alarm,
    Settings(Settings),
    BackupBattery,
}

#[derive(Clone, Copy, PartialEq, Debug)]
pub enum Settings {
    ClockHours,
    ClockMinutes,
    AlarmHours,
    AlarmMinutes,
}

#[derive(Clone, Copy, Debug)]
pub enum Event {
    Encoder(EncoderEvent),
    ResetButton,
    Timer(TimerEvent),
    VBUSDisconnected,
    VBUSConnected,
}

#[derive(Clone, Copy, Debug)]
pub enum TimerEvent {
    PeriodicUpdate(u32), // Event contains RTC counter value
    AlarmTriggered,
    Timeout, // General timeout used for timing out settings/alarm
    Blink,   // Used for blinking the alarm and settings display
}

#[derive(Clone, Copy, Debug)]
pub enum EncoderEvent {
    Rotated(isize),
    ShortPressed,
    LongPressed,
}

pub trait StateMachine {
    fn next(&self, event: Event) -> State;
}

impl StateMachine for State {
    fn next(&self, event: Event) -> State {
        match self {
            State::Idle => match event {
                Event::Encoder(EncoderEvent::ShortPressed) => State::Settings(Settings::AlarmHours),
                Event::Encoder(EncoderEvent::LongPressed) => State::Settings(Settings::ClockHours),
                Event::VBUSDisconnected => State::BackupBattery,
                Event::Timer(TimerEvent::AlarmTriggered) => State::Alarm,
                _ => State::Idle,
            },

            State::Alarm => match event {
                Event::Encoder(encoder_event) => match encoder_event {
                    EncoderEvent::ShortPressed => State::Idle,
                    EncoderEvent::LongPressed => State::Idle,
                    _ => State::Alarm,
                },
                Event::Timer(TimerEvent::PeriodicUpdate(_)) => State::Alarm,
                Event::Timer(TimerEvent::Timeout) => State::Idle,
                _ => State::Alarm,
            },

            State::Settings(settings) => match event {
                Event::Encoder(EncoderEvent::Rotated(_)) => match settings {
                    Settings::ClockHours => State::Settings(Settings::ClockHours),
                    Settings::ClockMinutes => State::Settings(Settings::ClockMinutes),
                    Settings::AlarmHours => State::Settings(Settings::AlarmHours),
                    Settings::AlarmMinutes => State::Settings(Settings::AlarmMinutes),
                },
                Event::Encoder(EncoderEvent::ShortPressed) => match settings {
                    Settings::ClockHours => State::Settings(Settings::ClockMinutes),
                    Settings::ClockMinutes => State::Idle,
                    Settings::AlarmHours => State::Settings(Settings::AlarmMinutes),
                    Settings::AlarmMinutes => State::Idle,
                },
                Event::Timer(TimerEvent::Timeout) => State::Idle,
                _ => State::Settings(*settings),
            },

            State::BackupBattery => match event {
                Event::VBUSConnected => State::Idle,
                _ => State::BackupBattery,
            },
        }
    }
}

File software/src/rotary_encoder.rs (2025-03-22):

use {
    crate::{app::*, state_machine::*},
    rtic::Mutex,
    hal::{
        gpio::{Input, Pin, PullUp},
        gpiote::*,
        pac::{GPIOTE, QDEC},
        qdec::*,
    },
    nrf52833_hal as hal,
};

#[cfg(feature = "52833-debug")]
use core::fmt::Write;

const ROTARY_ENCODER_THRESHOLD_SEC: f32 = 0.1;
const LONG_PRESS_THRESHOLD_SEC: f32 = 0.5;
const DEBOUNCE_THRESHOLD_SEC: f32 = 0.1;

pub(crate) fn init(
    qdec: QDEC,
    gpiote: GPIOTE,
    rotation_pins: Pins,
    switch_pin: Pin<Input<PullUp>>,
) -> (Qdec, Gpiote) {
    let qdec = Qdec::new(qdec, rotation_pins, SamplePeriod::_2048us);
    qdec.enable_interrupt(NumSamples::_1smpl)
        .debounce(true)
        .enable();

    let gpiote = Gpiote::new(gpiote);
    gpiote
        .channel0()
        .input_pin(&switch_pin)
        .hi_to_lo()
        .enable_interrupt();
    gpiote
        .channel1()
        .input_pin(&switch_pin)
        .lo_to_hi()
        .enable_interrupt();

    (qdec, gpiote)
}

pub(crate) fn handle_qdec_interrupt(mut cx: qdec_interrupt::Context) {
    #[cfg(feature = "52833-debug")]
    cx.shared.rtt_hw.lock(|rtt_hw| {
        writeln!(rtt_hw, "QDEC interrupt").ok();
    });
    let direction = cx.shared.qdec.lock(|qdec| {
        qdec.reset_events();
        -qdec.read() // Inverted direction
    });

    let now = cortex_m::peripheral::DWT::cycle_count();
    let elapsed_cycles = now.wrapping_sub(*cx.local.last_rotation);
    let elapsed_time = elapsed_cycles as f32 / 64_000_000.0;

    // Filter out debounce noise
    if !(elapsed_time <= ROTARY_ENCODER_THRESHOLD_SEC) {
        *cx.local.last_rotation = now;

        let direction = match direction > 0 {
            true => 1,
            false => -1,
        };
        state_machine::spawn(Event::Encoder(EncoderEvent::Rotated(direction as isize))).ok();
    }
}

pub(crate) fn handle_gpiote_interrupt(mut cx: gpiote_interrupt::Context) {
    #[cfg(feature = "52833-debug")]
    cx.shared.rtt_hw.lock(|rtt_hw| {
        writeln!(rtt_hw, "GPIOTE interrupt").ok();
    });
    let now = cortex_m::peripheral::DWT::cycle_count();
    let elapsed_cycles = now.wrapping_sub(*cx.local.last_press);
    let elapsed_time = elapsed_cycles as f32 / 64_000_000.0;

    // Filter out debounce noise
    if elapsed_time <= DEBOUNCE_THRESHOLD_SEC {
        return;
    }

    // Press event
    cx.shared.gpiote.lock(|gpiote| {
    if gpiote.channel0().is_event_triggered() {
        gpiote.channel0().reset_events();
        *cx.local.last_press = now;
    }});
    // Release event
    cx.shared.gpiote.lock(|gpiote| {
    if gpiote.channel1().is_event_triggered() {
        gpiote.channel1().reset_events();

        match elapsed_time > LONG_PRESS_THRESHOLD_SEC {
            true => state_machine::spawn(Event::Encoder(EncoderEvent::LongPressed)).ok(),
            false => state_machine::spawn(Event::Encoder(EncoderEvent::ShortPressed)).ok(),
        };
    }});
}

pub(crate) fn disable_interrupts(mut cx: rotary_disable_interrupts::Context) {
    cx.shared.gpiote.lock(|gpiote| {
        gpiote.port().disable_interrupt();
    }); 
    cx.shared.qdec.lock(|qdec| {
        qdec.disable_interrupt();
    });
}

pub(crate) fn enable_interrupts(mut cx: rotary_encoder_enable_interrupts::Context) {
    cx.shared.gpiote.lock(|gpiote| {
        gpiote.port().enable_interrupt();
    }); 
    cx.shared.qdec.lock(|qdec| {
        qdec.enable_interrupt(NumSamples::_1smpl)
            .debounce(true)
            .enable();
    });
}

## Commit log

2025-02-03 Add schematic (#2)
    * Add assets
    * Initial backup battery commit
    * Add basic Schottky setup
    Missing footprints for diodes
    * Update changelog
    * Update goals
    * add base schematic and rotary encoder
    * fix display link
    * add oled display
    * add rotary encoder footprint
    * Update CHANGELOG.md
    * add amplifier and speaker symbols
    * opt and fan HW
    * added change to changelog
    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
    [HD-EMC1203-LW20-R.step, MMBT2222A_DG_215.step, backup_battery.kicad_pcb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]
2025-02-04 Finish first hardware iteration (#3)
    * Add Schottky rectifier symbol and footprint
    * import components to PCB
    * Fix relative paths
    * Change transducer symbol
    * Update PCB and Schema after symbol change
    * Remove separate schematics
    * did some layout and routing
    CHANGELOG
    * Changelog
    * move humidifier to fan/SD_MODE control pin, small fixes
    * Update README.md
    * Add diode footprint
    * finished placing components
    * fix references
    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
    [SS16.step, ZLLS500TA.step, backup_battery.kicad_pcb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]
2025-02-06 Add pull-up resistors to display
    [base.kicad_pcb, base.kicad_sch]
2025-03-03 LED example (#4)
    * blinking working
    * Enable unsafe code denial
    * Remove trace, clean up
    * PWM dimmable LED working
    * Add proper UICR handling
    ---------
2025-03-07 Examples for reset button, rotary encoder and thermistor (#8)
    * Reset button implemented
    * small fix
    * Reset button implemented
    * Rotary encoder, interrupt handling and debouncing
    * Rotary encoder push switch
    * Reset button implemented
    * Rotary encoder, interrupt handling and debouncing
    * Rotary encoder push switch
    * Thermistor working
    * Fix warnings, update measured vdd
    * small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
    [reset_btn.rs, rotary_encoder.rs, thermistor.rs]
2025-03-07 Backup battery mode (#9)
    * Add backup mode example
    * Add interrupt counter
    * Improve testability
    * Backup mode working
    * Split into two examples
2025-03-12 Display_SW Done (#13)
    * divided up everything to make the locks more tight
    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
    [display.rs]
2025-03-13 add haptic actuator example (#14)
    * add haptic actuator
    * Update CHANGELOG.md and TODO.md
2025-03-18 Add cli (#15)
    * CLI working
    * CLI time printing works
    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
2025-03-19 State machine integration (#16)
    * State machine draft
    * Add alarm WFI
    * Remove states that were not really states
    * Add enum state machine
    * Add missing steps value
    * Integrate RTC timer
    * Refactor rtc to take shared context
    * Move rtc interrupt handling
    * Integrate thermistor
    * Integrate rotary encoder and reset button
    * Move uicr handling
    * Integrate pwm and led into state machine
    * Make PWM ramp up slower
    * Cargo lock changes
    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
    [display.rs, gpio.rs, led.rs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]
2025-03-20 Fix fan example (#17)
    [fan.rs]
2025-03-20 PWM example (#18)
2025-03-22 Final integration (#19)
    * No more pain
    * More pain
    * Torture
    * Speaker not working
    * Last minute changes
    ---------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
    [cli.rs, display.rs, gpio.rs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]
